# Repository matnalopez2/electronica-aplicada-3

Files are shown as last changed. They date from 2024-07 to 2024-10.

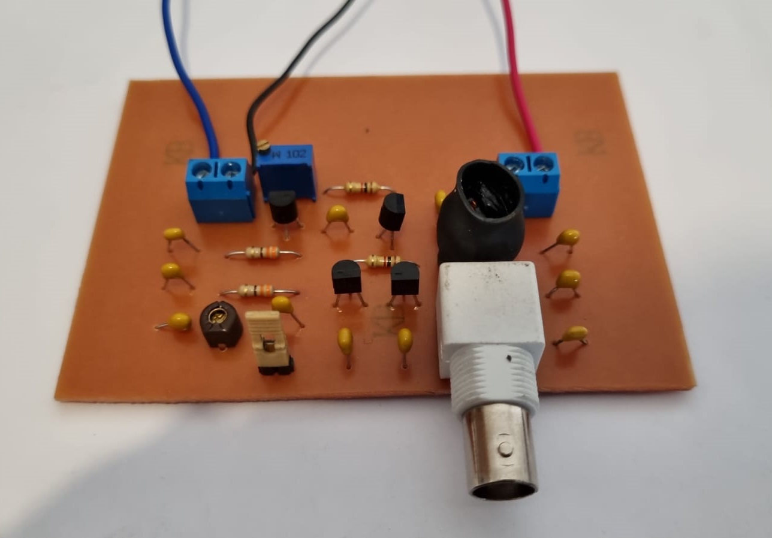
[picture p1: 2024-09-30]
Recursos/06-Placa terminada/02_placaSuperior.jpeg

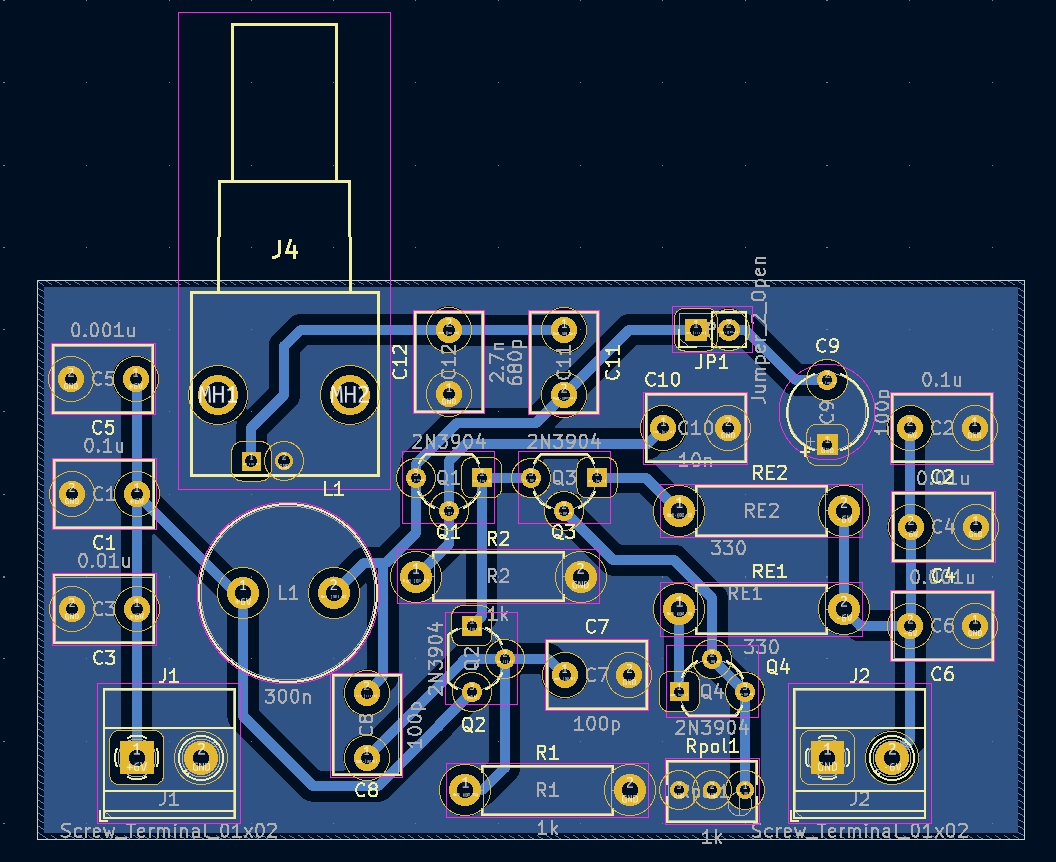
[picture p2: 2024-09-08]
Recursos/Kicad/pcb_ruteo_01.jpg

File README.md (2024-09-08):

# Trabajo Práctico Obligatorio - Electrónica Aplicada 3

## Oscilador con Par Diferencial de Frecuencia Variable

### Introducción

Este proyecto tiene como objetivo desarrollar un oscilador con par diferencial de frecuencia variable. Se busca cumplir con especificaciones técnicas exigentes para asegurar un desempeño óptimo.

### Especificaciones del Proyecto

* **Frecuencia central:** 12 MHz
* **Tensión de salida:** 1 volt pico
* **Capacidad de carga:** Apto para cargar con 50 ohm
* **Funciones adicionales:** Ajuste de amplitud o control automático de amplitud

### Contenido del Repositorio

El repositorio contiene los siguientes elementos:

#### Microcap
 Archivos realizados con el software Microcap, donde existen 3 proyectos:
  * `Oscilador ideal.cir`: Primera parte, con fuente de corriente ideal.
  * `Oscilador real con valores comerciales.cir`: Segunda parte, incluye la fuente espejo y componentes con valores comerciales.
  * `Oscilador real con valores medidos.cir`: Tercera parte, pendiente de actualización con componentes medidos.

#### Mathcad

Archivos realizados con el software Mathcad, descontinuado su avance y mantenidos solo para referencia.

#### pcb_oscilador

Archivos realizados con el software Kicad, para diseño del PCB.

#### Recursos

Recursos utilizados para el desarrollo del Jupyter Notebook y anotaciones como mediciones realizadas en el laboratorio.

#### `Informe.ipynb`

Archivo Jupyter Notebook con el informe del proyecto, incluyendo el desarrollo matemático y capturas de pantalla del software de simulación.

## Licencia

Este proyecto está bajo la Licencia MIT, lo que permite el uso, modificación y distribución del contenido con la debida atribución. Consulta el archivo LICENSE para más detalles.

## Contacto

Para más información sobre el proyecto o consultas adicionales, puedes comunicarte a: [matias@matnalopez.com.ar](mailto:matias@matnalopez.com.ar)

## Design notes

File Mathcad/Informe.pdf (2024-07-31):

Trabajo Práctico:

Oscilador con par diferencial de frecuencia variable, frecuencia central 12 MHz, tensión de salida 1 volt pico, apto para cargar con 50 ohm, una vez cumplido agregar ajuste de amplitud. O control aut de amplitud.

Datos:
f0≔12 ⋅ 10⁶ | a≔2 | Q0≔100
RL≔50 | b≔5

Para comenzar a trabajar, se asume una bobina de 300nHy:

L≔300 ⋅ 10⁻⁹

Con esta bobina, se calcula la capacidad equivalente para que el circuito resuene en 12MHz.

Ceq≔―――――=

1
((2 ⋅π⋅ f0)) ⋅

2
L

586.349 ⋅ 10⁻¹²

A partir de este punto, se comienza a calcular el capacitor C4, de forma de cumplir el enunciado y poder cargar con 50ohm a la salida. Para ello, se define que XC4 debe ser aproximadamente 10 veces menor a RL y se asume:

XC4≔5

Aquí se podrá calcular C4 y luego C3. Se define que b=5.

C4≔―――――=

1 2 ⋅π⋅ f0 ⋅XC4 | 2.653 ⋅ 10⁻⁹ | C3≔――=

C4
b-1

663.146 ⋅ 10⁻¹²

Por último, se obtiene la capacidad equivalente del divisor capacitivo de la salida:

| Ceq2≔―――= C3 ⋅C4
| C3+C4 | 530.516 ⋅ 10⁻¹²

Se continúa calculando la capacidad equivalente de los capacitores C1 y C2. Hasta aquí no se considera Cvariable en el diseño del oscilador.

Ceq1≔Ceq-Ceq2=55.833 ⋅ 10⁻¹²

C2≔a⋅Ceq1=111.666 ⋅ 10⁻¹² | C1≔――=

C2
a-1

111.666 ⋅ 10⁻¹²

Como se trabaja con una bobina ideal, se procede a calcular su Rt y también la resistencia

RL reflejada, para obtener la Rtotal siendo el paralelo entre ambas:
Rt≔Q0 ⋅ 2 ⋅π⋅ f0 ⋅L=2.262 ⋅ 10³ | RL'≔RL⋅ b =

2 1.25 ⋅ 10³

Rtot≔―――=

Rt⋅RL'
Rt+RL'

805.09

A partir de ahora, ya se cuenta con todos los componentes calculados y resta verificar que la tensión de salida cumpla con lo indicado en el enunciado, entonces se asume IG = 10mA y se calcula tensión de colector y de salida:

IG≔10 ⋅ 10⁻³ | Vcol≔IG⋅―⋅ | =
| 2 π | Rtot 5.125
| Vsal≔――= Vcol b | 1.025

Se puede observar que el oscilador tiene 1.014V de tensión pico de salida.
Se observan 16.3V de tensión máxima pico de colector, 7.7V de tensión mínima de colector, montado en una continua de 12V y resultando en una tensión pico de colector de 4.69V.
Tension_Continua≔――――+ | =
| 16.3-7.7
| 2 | 7.7 12

Tension_Pico_de_Colector≔16.3-Tension_Continua=4.3

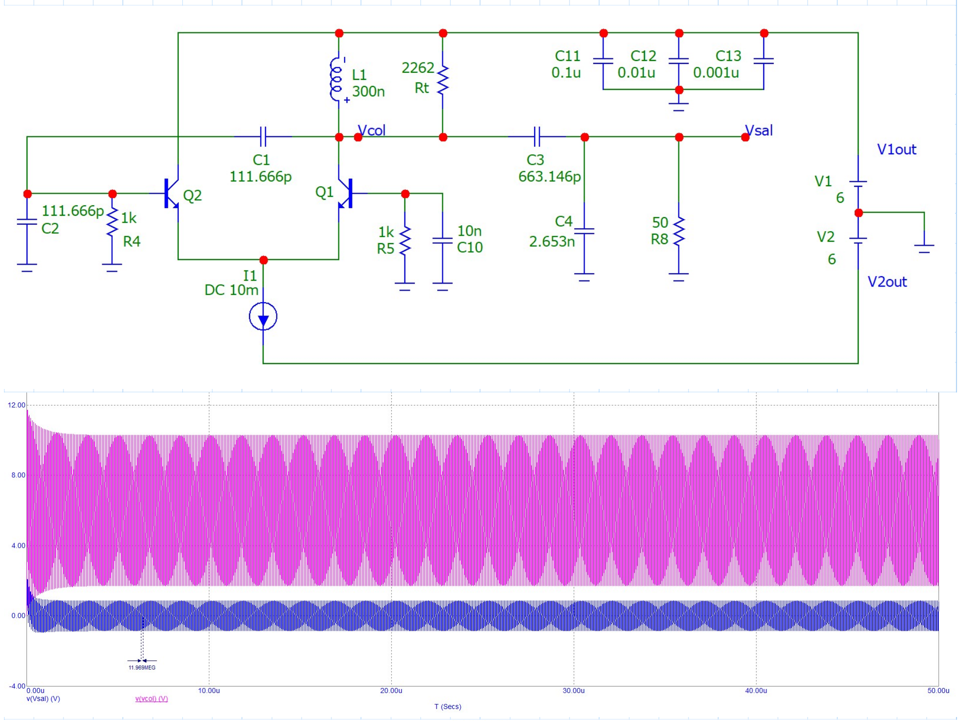
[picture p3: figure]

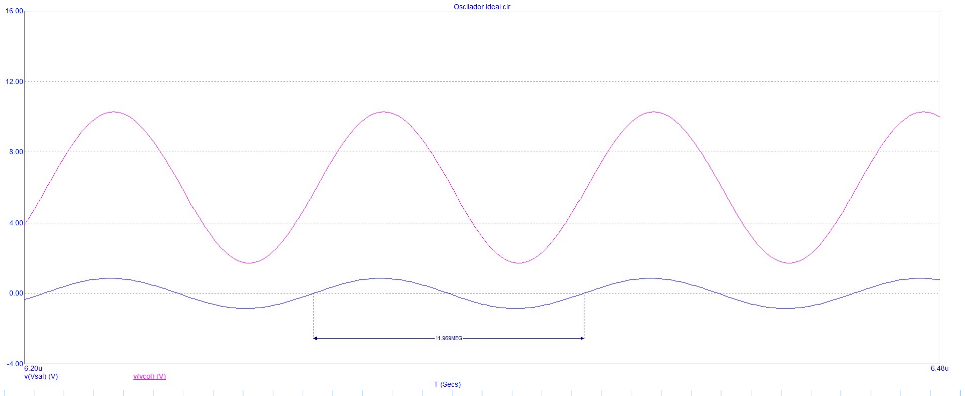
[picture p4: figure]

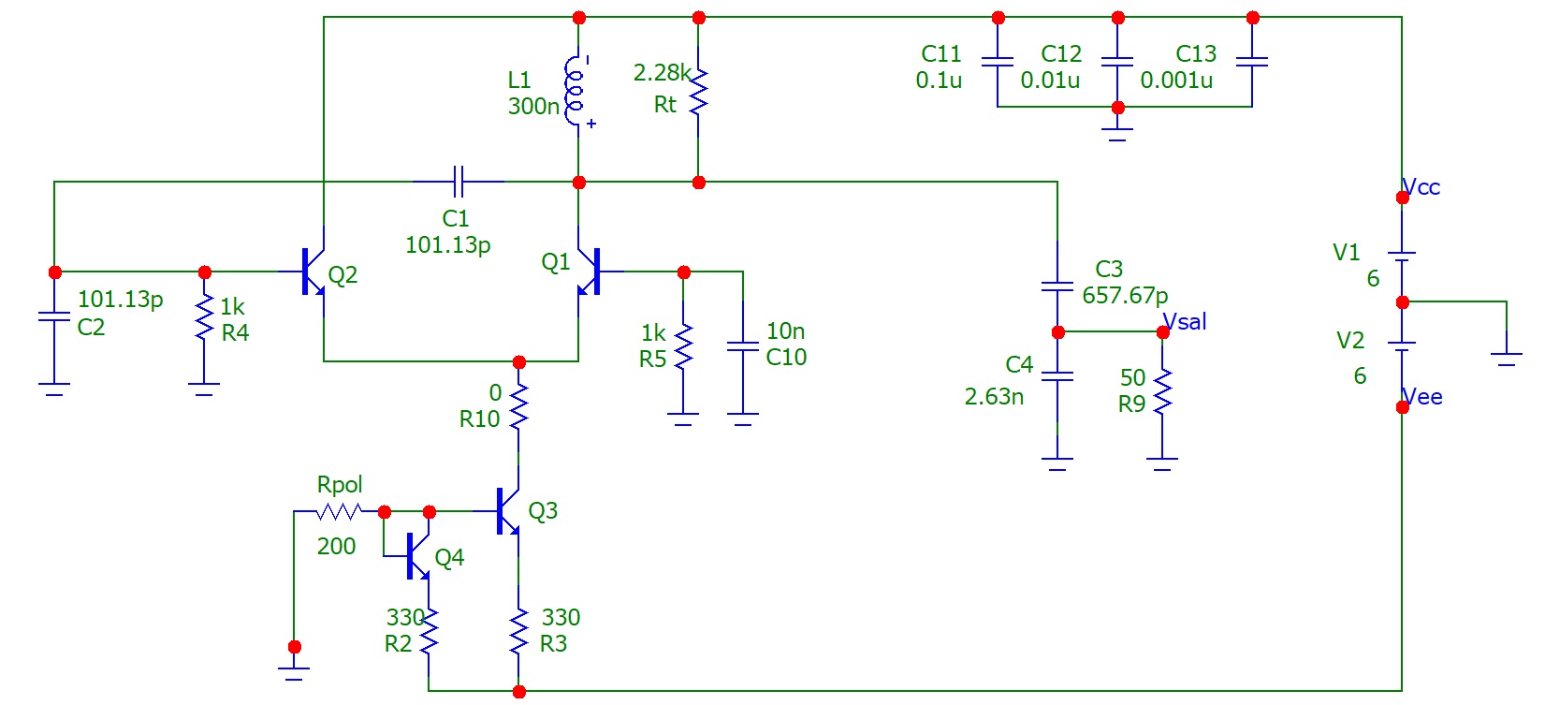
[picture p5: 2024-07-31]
Recursos/02-Oscilador ideal con fuente espejo/01_circuito_ideal_con_fuente_espejo_esquematico.jpg

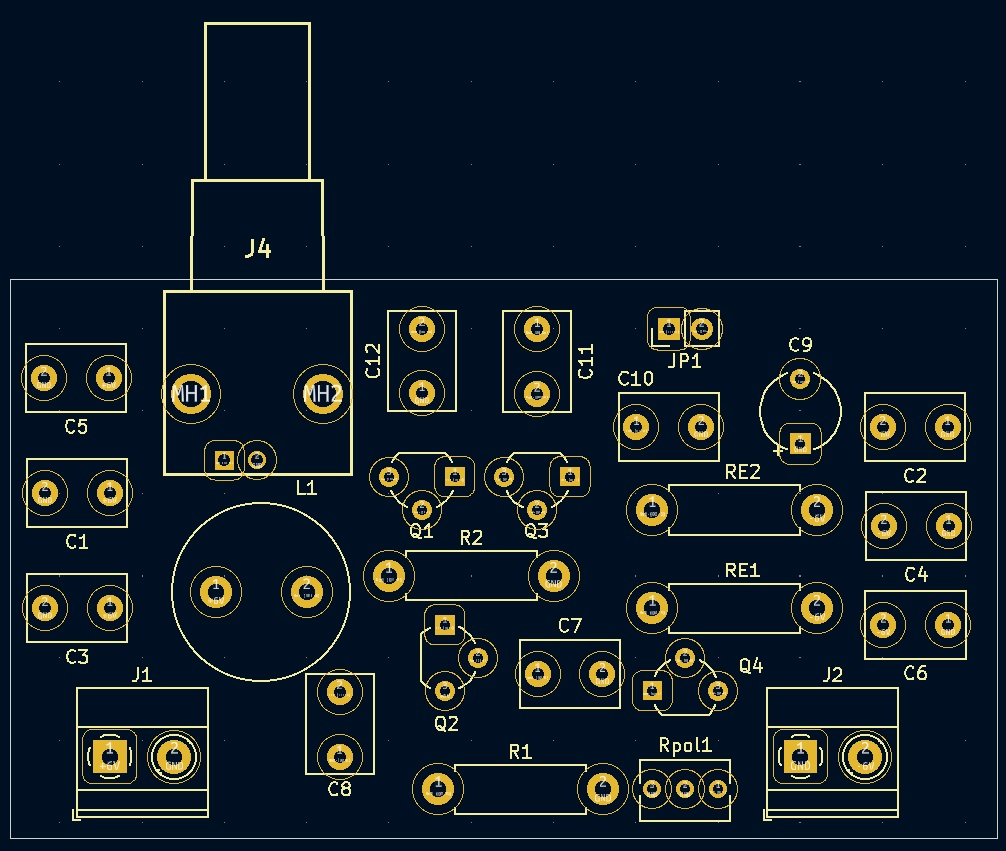
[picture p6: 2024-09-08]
Recursos/Kicad/pcb_ruteo_04.jpg

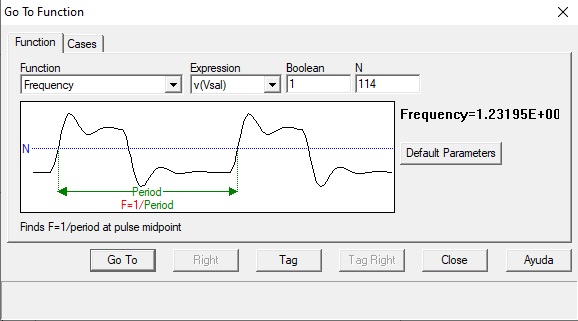
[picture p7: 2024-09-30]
Recursos/05-Oscilador con mediciones FRA/10_salida_frecuencia.jpg

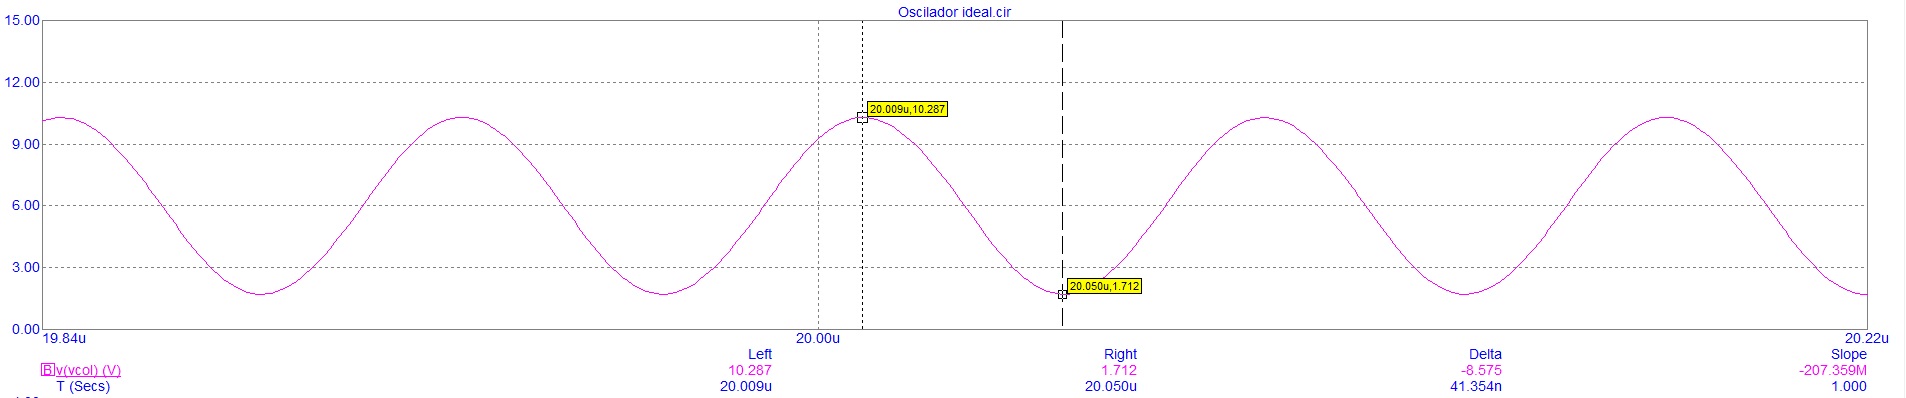
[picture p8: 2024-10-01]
Recursos/01-Oscilador ideal/02_circuito_ideal_con_fuente_ideal_Vcol_v2.jpg

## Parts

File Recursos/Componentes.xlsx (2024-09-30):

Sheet: Hoja1
ID | Detalle | Codigo | Valor comercial | Valor medido
C1 | Capacitor bipolar | 104 | 100 n |  |  | 681 | 222 | 332
C10 | Capacitor bipolar | 103 | 10 n |  |  | 695.8 | 2.015 | 3.178
C11 | Capacitor bipolar | 681 | 680 p | 667 p |  | 694.3 | 2.02 | 3.157
C12 | Capacitor bipolar |  | 2.7 n | 2,02 n |  | 720.8 | 2.06 | 3.153
C2 | Capacitor bipolar | 104 | 100 n |  |  | 694.8
C3 | Capacitor bipolar | 103 | 10 n |  |  | 667.2
C4 | Capacitor bipolar | 103 | 10 n
C5 | Capacitor bipolar | 102 | 1 n
C6 | Capacitor bipolar | 102 | 1 n
C7 | Capacitor bipolar | 101 | 100 p | 103,8 p
C8 | Capacitor bipolar | 101 | 100 p | 101,4 p
C9 | Capacitor variable | MARRON | 101p
J4 | Conector VNA |  | Conector VNA
L1 | Bobina |  | 300 n | 280 n |  | NO HAY 2.7nF | 2,2nF
Q1 | Transistor |  | 2N3904 |  |  |  | 3,3nF
Q2 | Transistor |  | 2N3904
Q3 | Transistor |  | 2N3904 |  |  |  | Medimos para 372pF
Q4 | Transistor |  | 2N3904 |  |  | Mhz | Q | Capacidad [pF]
R1 | Resistor | 1k | 1k |  | Q = | 13.5 | 122 | 455
R2 | Resistor | 1k | 1k |  |  | 14 | 125 | 425
RE1 | Trimmer |  | 500 ohm |  |  | 15 | 130 | 370
RE2 | Trimmer |  | 500 ohm
Rpol1 | Trimmer | 102 | 1k |  |  |  | Aproximamos el Q en 120 porque no llegamos con el instrumento a medir

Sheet: BOM
Detalle | Valor | Comprar | valor | micro [u] | nano [n] | pico [p]
Capacitor multicapa | 1 n | 10 | 0.001 u | 0.001 | 1 | 1000
Capacitor multicapa | 10 n | 15 | 0.01 u | 0.01 | 10 | 10000
Capacitor multicapa | 100 n | 10 | 0.1 u | 0.1 | 100 | 100000
Capacitor multicapa | 100 p | 10 | 100 p | 0.0001 | 0.1 | 100
Resistencia | 1k | 10 | 2.7 n | 0.0027 | 2.7 | 2700
Potenciometro | 1k | 6 | 680 p | 0.00068 | 0.68 | 680
Capacitor multicapa | 2.7 n | 5 | 10 n | 0.01 | 10 | 10000
Transistor | 2N3904 | 8
Capacitor multicapa | 680 p | 5

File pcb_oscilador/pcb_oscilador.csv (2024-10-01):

Id | Identificador | Huella | Cantidad | Identificación | Suministrador y ref
1 | L1 | L_Radial_D13.5mm_P7.00mm_Fastron_09HCP | 1 | 300n
2 | C3,C4 | C_Disc_D7.5mm_W5.0mm_P5.00mm | 2 | 0.01u
3 | J4 | B6252H5NPP3G50 | 1 | Conn_Coaxial
4 | J2,J1 | TerminalBlock_Phoenix_MKDS-1,5-2_1x02_P5.00mm_Horizontal | 2 | Screw_Terminal_01x02
5 | C9 | CP_Radial_Tantal_D6.0mm_P5.00mm | 1 | 100p
6 | C11 | C_Disc_D7.5mm_W5.0mm_P5.00mm | 1 | 680p
7 | C1,C2 | C_Disc_D7.5mm_W5.0mm_P5.00mm | 2 | 0.1u
8 | C8,C7 | C_Disc_D7.5mm_W5.0mm_P5.00mm | 2 | 100p
9 | Q1,Q2,Q4,Q3 | TO-92_Wide | 4 | 2N3904
10 | RE1,RE2 | R_Axial_DIN0411_L9.9mm_D3.6mm_P12.70mm_Horizontal | 2 | 330
11 | R1,R2 | R_Axial_DIN0411_L9.9mm_D3.6mm_P12.70mm_Horizontal | 2 | 1k
12 | JP1 | PinHeader_1x02_P2.54mm_Vertical | 1 | Jumper_2_Open
13 | C5,C6 | C_Disc_D7.5mm_W5.0mm_P5.00mm | 2 | 0.001u
14 | C12 | C_Disc_D7.5mm_W5.0mm_P5.00mm | 1 | 2.7n
15 | C10 | C_Disc_D7.5mm_W5.0mm_P5.00mm | 1 | 10n
16 | Rpol1 | Potentiometer_Bourns_3266Y_Vertical | 1 | 1k

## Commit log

2024-07-31 commit inicial
    [Oscilador.csv, Oscilador.kicad_pcb, Oscilador.kicad_sch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]
2024-09-01 orden en repo, kicad y reimportacion de las fotos del notebook correctamente ordenadas en cada directorio
    [Oscilador.csv, Oscilador.kicad_pcb, Oscilador.kicad_sch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]
2024-09-01 correccion en importacion de imagen
2024-09-01 agregado de calculo de f_0_final, pendiente revisar desde el inicio tomar C4 como 2.2n en vez de 2.7n
2024-09-08 nuevo proyecto kicad && esquematico con ERC correcto
    [pcb_oscilador.kicad_pcb, pcb_oscilador.kicad_sch]
2024-09-08 placa ruteada con DRC correcto. fotos de modelo 3D guardadas en recursos
    [pcb_oscilador.kicad_pcb]
2024-09-08 fotos agregadas al notebook
    [pcb_oscilador.kicad_pcb, pcb_oscilador.kicad_sch]
2024-09-08 orden del repo
    [Oscilador.csv, Oscilador.kicad_pcb, Oscilador.kicad_sch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]
2024-09-08 actualizar readme y orden de repo
2024-09-30 agregado de info sobre mediciones en FRA, incluyendo excel con mediciones, fotos de placa terminada, simulaciones con valores medidos
    [Componentes.xlsx]
2024-10-01 empiezo a emprolijar el notebook
2024-10-01 check de importacion de fotos
2024-10-01 upgrade de notebook. buscar el 'LLEGAMOS HASTA ACA' para seguir
2024-10-01 checkpoint de entrega
    [pcb_oscilador.csv]
2024-10-01 Entrega final :)
    [Componentes.xlsx]
